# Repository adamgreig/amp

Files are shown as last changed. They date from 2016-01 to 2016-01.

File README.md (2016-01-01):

# Adam Magic Probe

A clone of the wonderful
[Black Magic Probe](http://www.blacksphere.co.nz/main/blackmagic) but in KiCAD 
and with a few small hardware tweaks.

As such this work is also distributed under the CC-BY-SA licence.

This is a really useful tool for ARM development and I'm incredibly grateful 
that it's open hardware and firmware. You should consider buying one!

## Changes From Black Magic Mini

* MicroUSB port
* No LEDs
* Cheaper, higher current LDO
* TagConnect for programming the host STM32

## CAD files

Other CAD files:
amp-F.Paste.dxf

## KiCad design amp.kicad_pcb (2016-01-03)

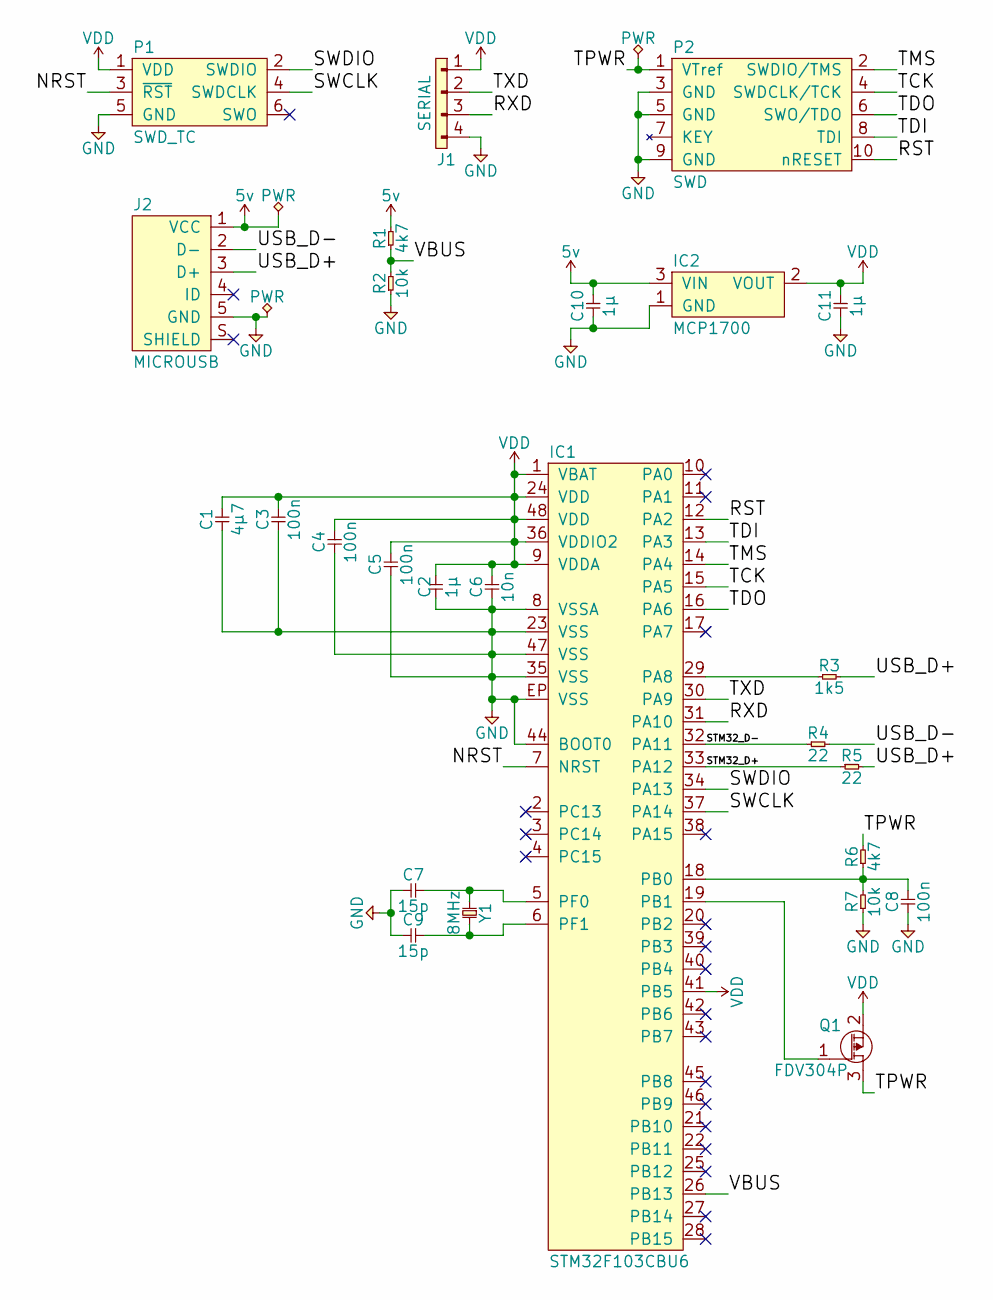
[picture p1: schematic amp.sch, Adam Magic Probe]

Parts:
C1: 4µ7; 0603
C2, C10, C11: 1µ; 0603
C3, C4, C5, C8: 100n; 0402
C6: 10n; 0402
C7, C9: 15p; 0402
IC1: STM32F103CBU6; QFN-48-EP-ST; Farnell 2060891
IC2: MCP1700; SOT-23; Farnell 1296592
J1: SERIAL; SM04B-PASS
J2: MICROUSB; MICROUSB_MOLEX_47589-0001; Farnell 1568023
P1: SWD_TC; TC2030-NL
P2: SWD; FTSH-105-01-L-DV-K
Q1: FDV304P; SOT-23; Farnell 9846123
R1, R6: 4k7; 0402
R2, R7: 10k; 0402
R3: 1k5; 0402
R4, R5: 22; 0402
Y1: 8MHz; XTAL-50x32; Farnell 2101329

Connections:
5v: C10.2, IC2.3 (VIN), J2.1 (VCC), R1.2
/NRST: IC1.7 (NRST), P1.3 (~RST)
/RST: IC1.12 (PA2), P2.10 (nRESET)
/RXD: IC1.31 (PA10), J1.3
/STM32_D+: IC1.33 (PA12), R5.1
/STM32_D-: IC1.32 (PA11), R4.1
/SWCLK: IC1.37 (PA14), P1.4 (SWDCLK)
/SWDIO: IC1.34 (PA13), P1.2 (SWDIO)
/TCK: IC1.15 (PA5), P2.4 (SWDCLK/TCK)
/TDI: IC1.13 (PA3), P2.8 (TDI)
/TDO: IC1.16 (PA6), P2.6 (SWO/TDO)
/TMS: IC1.14 (PA4), P2.2 (SWDIO/TMS)
/TPWR: P2.1 (VTref), Q1.3 (D), R6.2
/TXD: IC1.30 (PA9), J1.2
/USB_D+: J2.3 (D+), R3.2, R5.2
/USB_D-: J2.2 (D-), R4.2
/VBUS: IC1.26 (PB13), R1.1, R2.2
GND: C1.1, C2.1, C3.1, C4.1, C5.1, C6.1, C7.1, C8.1, C9.1, C10.1, C11.1, IC1.8 (VSSA), IC1.23 (VSS), IC1.35 (VSS), IC1.44 (BOOT0), IC1.47 (VSS), IC1.EP (VSS), IC2.1 (GND), J1.4, J2.5 (GND), P1.5 (GND), P2.3 (GND), P2.5 (GND), P2.9 (GND), R2.1, R7.1
unnamed: C7.2, IC1.5 (PF0), Y1.1
unnamed: C8.2, IC1.18 (PB0), R6.1, R7.2
unnamed: C9.2, IC1.6 (PF1), Y1.2
unnamed: IC1.19 (PB1), Q1.1 (G)
unnamed: IC1.29 (PA8), R3.1
VDD: C1.2, C2.2, C3.2, C4.2, C5.2, C6.2, C11.2, IC1.1 (VBAT), IC1.9 (VDDA), IC1.24 (VDD), IC1.36 (VDDIO2), IC1.41 (PB5), IC1.48 (VDD), IC2.2 (VOUT), J1.1, P1.1 (VDD), Q1.2 (S)

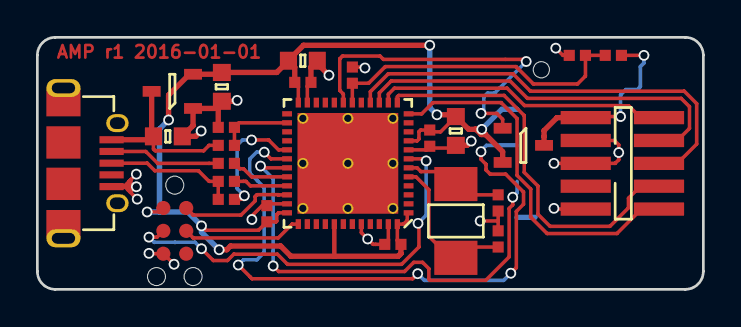
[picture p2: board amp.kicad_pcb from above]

Board: 2 copper layers, 37.0 x 14.0 mm, 26 parts (1 on the bottom side), 24 nets.

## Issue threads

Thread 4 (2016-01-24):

flip swd connector around?

adamgreig, 2016-01-24:

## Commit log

2016-01-01 First layout of schematic.
    [amp.kicad_pcb, amp.sch]
2016-01-01 Only need PB5 for version sensing
    [amp.sch]
2016-01-01 Specify the PFET
    [amp.sch]
2016-01-02 mostly routed go
    [amp.kicad_pcb, amp.sch]
2016-01-02 fully routed
    [amp.kicad_pcb, amp.sch]
2016-01-02 silk etc
    [amp-B.Cu.gbl, amp-B.Mask.gbs, amp-B.SilkS.gbo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]
2016-01-03 try swap to surface-mount swd connector
    [amp.kicad_pcb, amp.sch]
2016-01-03 ok, render gerbers for panel
    [.drl, amp-B.Cu.gbl, amp-B.Mask.gbs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]
2016-01-03 redo panel with new usb and jst connectors
    [amp-B.Cu.gbl, amp-B.Mask.gbs, amp-B.SilkS.gbo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]
2016-01-03 Add Farnell order codes
    [amp.sch]
2016-01-24 add good single-board stencil
    [amp-F.Paste.dxf]

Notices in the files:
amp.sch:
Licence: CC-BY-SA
